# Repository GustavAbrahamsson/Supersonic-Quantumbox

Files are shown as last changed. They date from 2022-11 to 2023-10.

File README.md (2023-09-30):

# Supersonic-Quantumbox

Multi-use digital guitar pedal

## Features
This pedal is an experiment in digital sound processing, powered by an ESP32-S2 running arduino. Designed to be ultra-flexible, it has a wide array of controls and indicators including knobs, lights, a screen, true bypass switch and easily available expansions. The high performance analog components from texas instruments handle 24bit data at 48KHz. 

## Todo
This project is still WIP, alot of things can be improved to make the pedal as easy and fun as possible.

- [x] Menu system for managing multiple effects at the same time
- [x] Nice looking and sturdy enclosure
- [ ] Add lots different of effects
- [ ] Expansion port for expression pedals, switches and more
- [ ] PCB revision with ESP32-S3, better power supply filtering, footprint fixes
- [ ] Wi-Fi configuration?

Apart from this the pedal is designed to be an exploration platform for different DSP techniques and algorithms, so new effects will hopefully be added continously.

## Creators
- Adam Anderson (@adaand00): PCB, low-level drivers
- Gustav Abrahamsson (@GustavAbrahamsson): PCB, Enclosure design

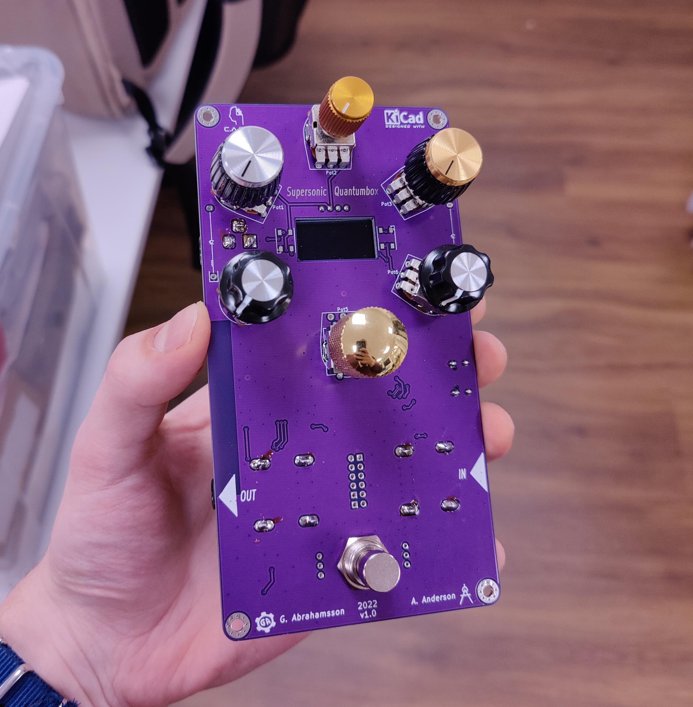
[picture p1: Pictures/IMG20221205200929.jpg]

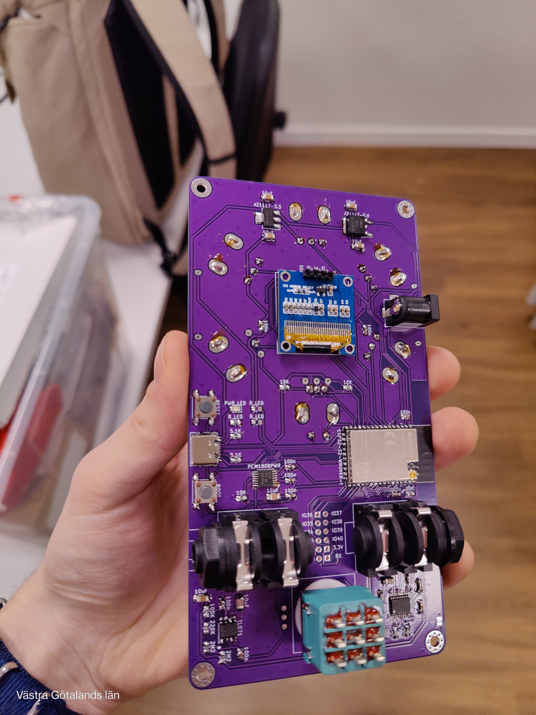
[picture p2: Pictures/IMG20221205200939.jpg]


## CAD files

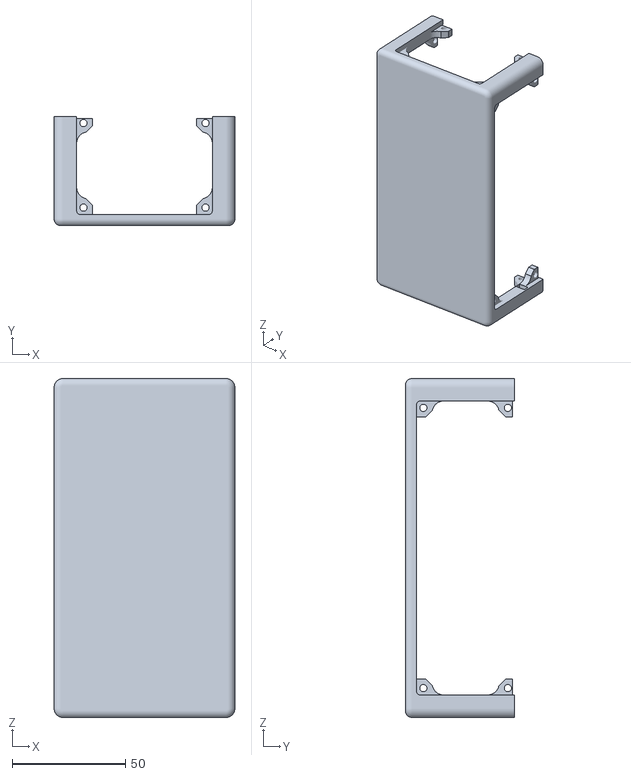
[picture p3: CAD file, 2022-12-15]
CAD/Bottom1.0.stl
80.0 x 48.4 x 150.0

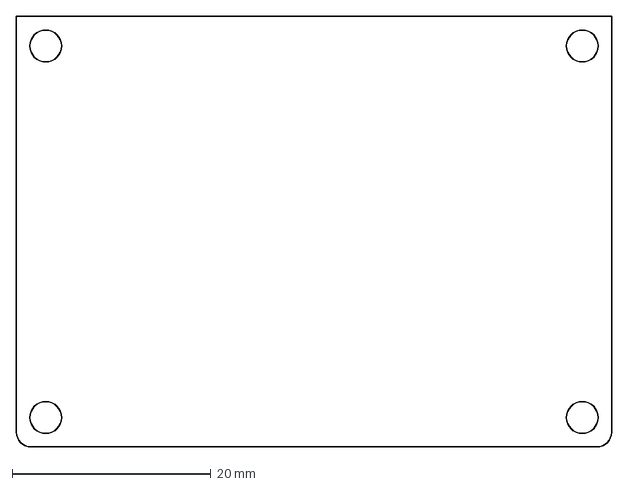
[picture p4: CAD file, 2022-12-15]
CAD/DXF/Short side 1.0.dxf
59.9 x 43.3 mm

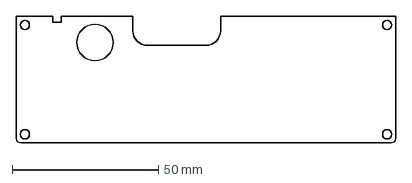
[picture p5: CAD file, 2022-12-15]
CAD/DXF/Right side 1.0.dxf
129.9 x 43.3 mm

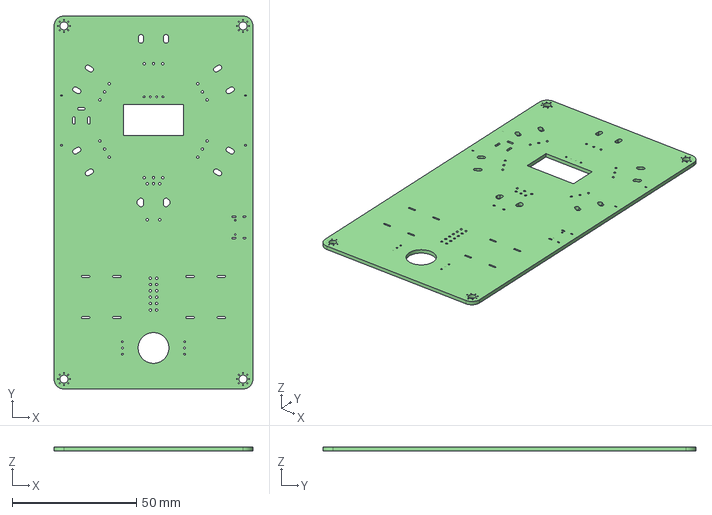
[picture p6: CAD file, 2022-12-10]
CAD/Supersonic Quantumbox.step
80.0 x 150.0 x 1.60 mm

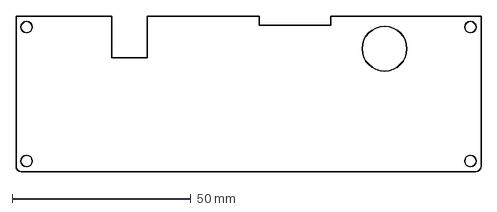
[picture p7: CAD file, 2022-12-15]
CAD/DXF/Left side 1.0.dxf
129.9 x 43.3 mm

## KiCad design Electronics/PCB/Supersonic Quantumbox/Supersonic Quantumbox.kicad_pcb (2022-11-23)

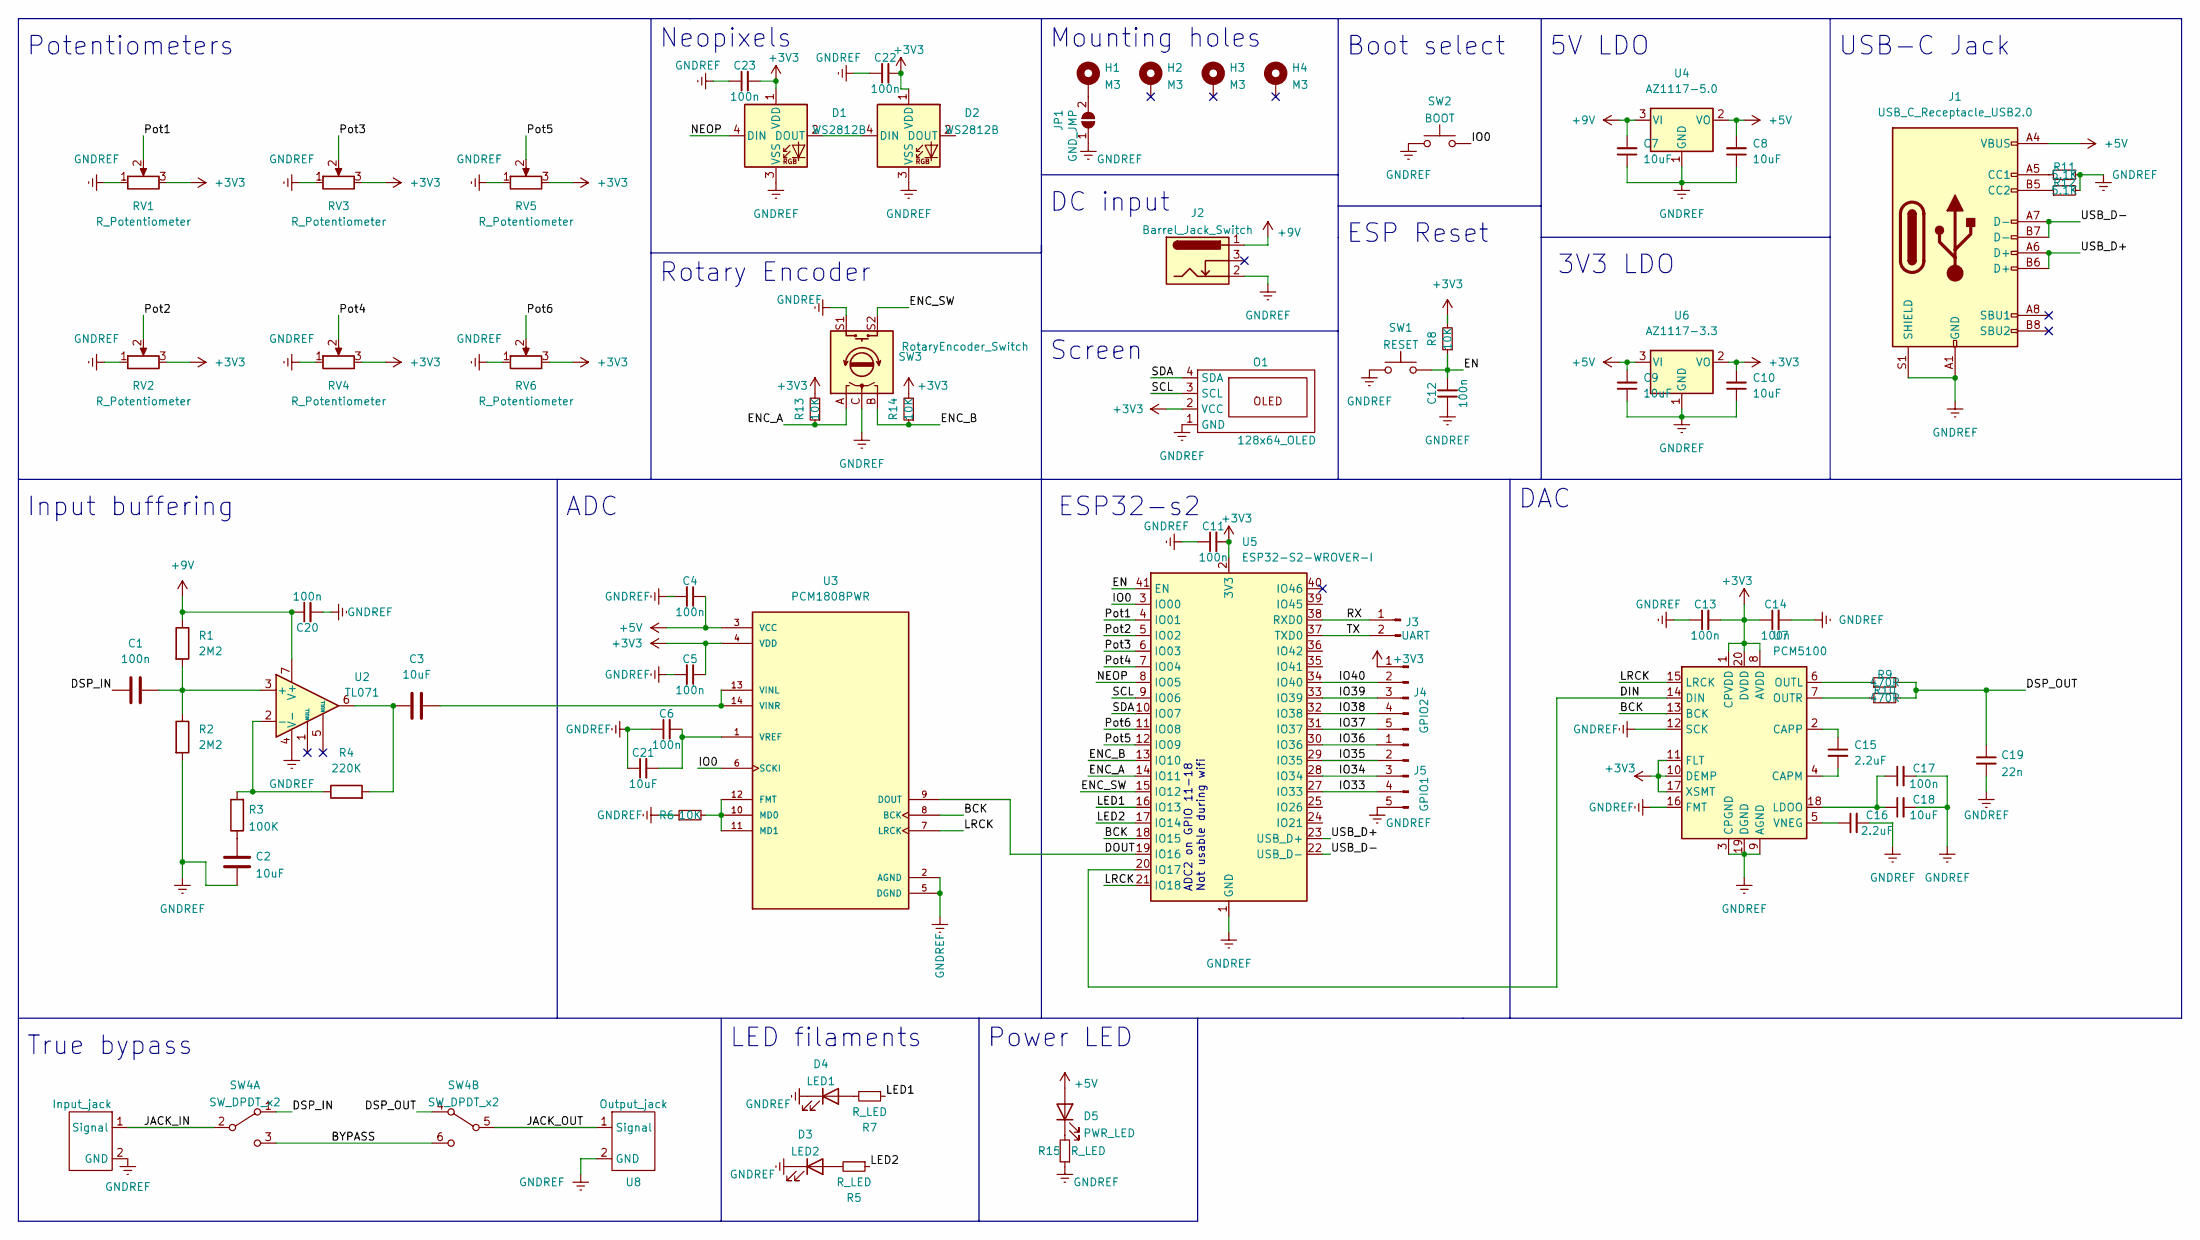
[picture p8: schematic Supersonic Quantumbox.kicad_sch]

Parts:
C1, C4, C5, C6, C11, C12, C13, C14, C17, C20, C22, C23: 100n; C_0805_2012Metric_Pad1.18x1.45mm_HandSolder
C2, C3, C7, C8, C9, C10, C18, C21: 10uF; C_1206_3216Metric
C15, C16: 2.2uF; C_1206_3216Metric
C19: 22n; C_0805_2012Metric_Pad1.18x1.45mm_HandSolder
D1, D2: WS2812B; LED_WS2812B_PLCC4_5.0x5.0mm_P3.2mm
D3: LED2; 38 mm LED
D4: LED1; 38 mm LED
D5: PWR_LED; LED_0805_2012Metric_Pad1.15x1.40mm_HandSolder
H1, H2, H3, H4: M3; MountingHole_3.2mm_M3_Pad_Via
J1: USB_C_Receptacle_USB2.0; USB_C_Receptacle_HRO_TYPE-C-31-M-12
J2: Barrel_Jack_Switch; BarrelJack_Horizontal
J3: UART; PinHeader_1x02_P2.54mm_Vertical
J4: GPIO2; PinSocket_1x05_P2.54mm_Vertical
J5: GPIO1; PinSocket_1x05_P2.54mm_Vertical
JP1: GND_JMP; SolderJumper-2_P1.3mm_Open_TrianglePad1.0x1.5mm
O1: 128x64_OLED; 128x64OLED
R1, R2: 2M2; R_0805_2012Metric_Pad1.20x1.40mm_HandSolder
R3: 100K; R_0805_2012Metric_Pad1.20x1.40mm_HandSolder
R4: 220K; R_0805_2012Metric_Pad1.20x1.40mm_HandSolder
R5, R7, R15: R_LED; R_0805_2012Metric_Pad1.20x1.40mm_HandSolder
R6, R8, R13, R14: 10K; R_0805_2012Metric_Pad1.20x1.40mm_HandSolder
R9, R10: 470R; R_0805_2012Metric_Pad1.20x1.40mm_HandSolder
R11, R12: 5.1K; R_0805_2012Metric_Pad1.20x1.40mm_HandSolder
RV1, RV2, RV3, RV4, RV5, RV6: R_Potentiometer; PBD12 potentiometer
SW1: RESET; SW_Push_1P1T_NO_6x6mm_H9.5mm
SW2: BOOT; SW_Push_1P1T_NO_6x6mm_H9.5mm
SW3: RotaryEncoder_Switch; RotaryEncoder_Alps_EC12E-Switch_Vertical_H20mm
SW4: SW_DPDT_x2; Stomp_switch
U1: Input_jack; MonoJack-SYS212
U2: TL071; SOIC-8_3.9x4.9mm_P1.27mm
U3: PCM1808PWR; SOP65P640X120-14N; PARTREV B
U4: AZ1117-5.0; TO-252-2
U5: ESP32-S2-WROVER-I; ESP32-S2-WROVER
U6: AZ1117-3.3; SOT-223-3_TabPin2
U7: PCM5100; TSSOP-20_4.4x6.5mm_P0.65mm
U8: Output_jack; MonoJack-SYS212

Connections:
+3V3: C5.1, C10.2, C11.2, C13.2, C14.1, C22.2, C23.2, D1.1 (VDD), D2.1 (VDD), J4.1, O1.2 (VCC), R8.2, R13.2, R14.2, RV1.3, RV2.3, RV3.3, RV4.3, RV5.3, RV6.3, U3.4 (VDD), U5.2 (3V3), U6.2 (VO), U7.1 (CPVDD), U7.8 (AVDD), U7.10 (DEMP), U7.11 (FLT), U7.17 (XSMT), U7.20 (DVDD)
+5V: C4.1, C8.2, C9.2, D5.2 (A), J1.A4 (VBUS), J1.A9 (VBUS), J1.B4 (VBUS), J1.B9 (VBUS), U3.3 (VCC), U4.2 (VO), U6.3 (VI)
+9V: C7.2, C20.1, J2.1, R1.1, U2.7 (V+), U4.3 (VI)
/BCK: U3.8 (BCK), U5.18 (IO15), U7.13 (BCK)
/BYPASS: SW4.3 (C), SW4.6 (C)
/DIN: U5.20 (IO17), U7.14 (DIN)
/DOUT: U3.9 (DOUT), U5.19 (IO16)
/DSP_IN: C1.1, SW4.1 (A)
/DSP_OUT: C19.1, R9.2, R10.2, SW4.4 (A)
/EN: C12.2, R8.1, SW1.2, U5.41 (EN)
/ENC_A: R13.1, SW3.A, U5.14 (IO11)
/ENC_B: R14.1, SW3.B, U5.13 (IO10)
/ENC_SW: SW3.S2, U5.15 (IO12)
/IO0: SW2.2, U3.6 (SCKI), U5.3 (IO00)
/IO33: J5.4, U5.27 (IO33)
/IO34: J5.3, U5.28 (IO34)
/IO35: J5.2, U5.29 (IO35)
/IO36: J5.1, U5.30 (IO36)
/IO37: J4.5, U5.31 (IO37)
/IO38: J4.4, U5.32 (IO38)
/IO39: J4.3, U5.33 (IO39)
/IO40: J4.2, U5.34 (IO40)
/JACK_IN: SW4.2 (B), U1.1 (Signal)
/JACK_OUT: SW4.5 (B), U8.1 (Signal)
/LED1: R7.1, U5.16 (IO13)
/LED2: R5.1, U5.17 (IO14)
/LRCK: U3.7 (LRCK), U5.21 (IO18), U7.15 (LRCK)
/NEOP: D1.4 (DIN), U5.8 (IO05)
/Pot1: RV1.2, U5.4 (IO01)
/Pot2: RV2.2, U5.5 (IO02)
/Pot3: RV3.2, U5.6 (IO03)
/Pot4: RV4.2, U5.7 (IO04)
/Pot5: RV5.2, U5.12 (IO09)
/Pot6: RV6.2, U5.11 (IO08)
/RX: J3.1, U5.38 (RXD0)
/SCL: O1.3 (SCL), U5.9 (IO06)
/SDA: O1.4 (SDA), U5.10 (IO07)
/TX: J3.2, U5.37 (TXD0)
/USB_D+: J1.A6 (D+), J1.B6 (D+), U5.23 (USB_D+)
/USB_D-: J1.A7 (D-), J1.B7 (D-), U5.22 (USB_D-)
GNDREF: C2.1, C4.2, C5.2, C6.1, C7.1, C8.1, C9.1, C10.1, C11.1, C12.1, C13.1, C14.2, C16.2, C17.2, C18.2, C19.2, C20.2, C21.1, C22.1, C23.1, D1.3 (VSS), D2.3 (VSS), D3.1 (K), D4.1 (K), J1.A1 (GND), J1.A12 (GND), J1.B1 (GND), J1.B12 (GND), J1.S1 (SHIELD), J2.2, J5.5, JP1.1 (A), O1.1 (GND), R2.2, R6.1, R11.2, R12.2, R15.1, RV1.1, RV2.1, RV3.1, RV4.1, RV5.1, RV6.1, SW1.1, SW2.1, SW3.C, SW3.S1, U1.2 (GND), U2.4 (V-), U3.2 (AGND), U3.5 (DGND), U4.1 (GND), U5.1 (GND), U5.26 (GND), U5.42 (GND), U5.43 (GND), U6.1 (GND), U7.3 (CPGND), U7.9 (AGND), U7.12 (SCK), U7.16 (FMT), U7.19 (DGND), U8.2 (GND)
unnamed: C1.2, R1.2, R2.1, U2.3 (+)
unnamed: C2.2, R3.1
unnamed: C3.1, R4.2, U2.6
unnamed: C3.2, U3.13 (VINL), U3.14 (VINR)
unnamed: C15.1, U7.2 (CAPP)
unnamed: C15.2, U7.4 (CAPM)
unnamed: C16.1, U7.5 (VNEG)
unnamed: C17.1, C18.1, U7.18 (LDOO)
unnamed: C6.2, C21.2, U3.1 (VREF)
unnamed: D1.2 (DOUT), D2.4 (DIN)
unnamed: D3.2 (A), R5.2
unnamed: D4.2 (A), R7.2
unnamed: D5.1 (K), R15.2
unnamed: H1.1, JP1.2 (B)
unnamed: J1.A5 (CC1), R11.1
unnamed: J1.B5 (CC2), R12.1
unnamed: R3.2, R4.1, U2.2 (-)
unnamed: R6.2, U3.10 (MD0), U3.11 (MD1), U3.12 (FMT)
unnamed: R9.1, U7.6 (OUTL)
unnamed: R10.1, U7.7 (OUTR)

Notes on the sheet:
ADC
Mounting holes
ESP Reset
True bypass
Screen
ESP32-s2
3V3 LDO
ADC2 on GPIO 11-18 Not usable during wifi
Power LED
LED filaments
Boot select
Rotary Encoder
DC input
DAC
Neopixels
Potentiometers
5V LDO
Input buffering
USB-C Jack

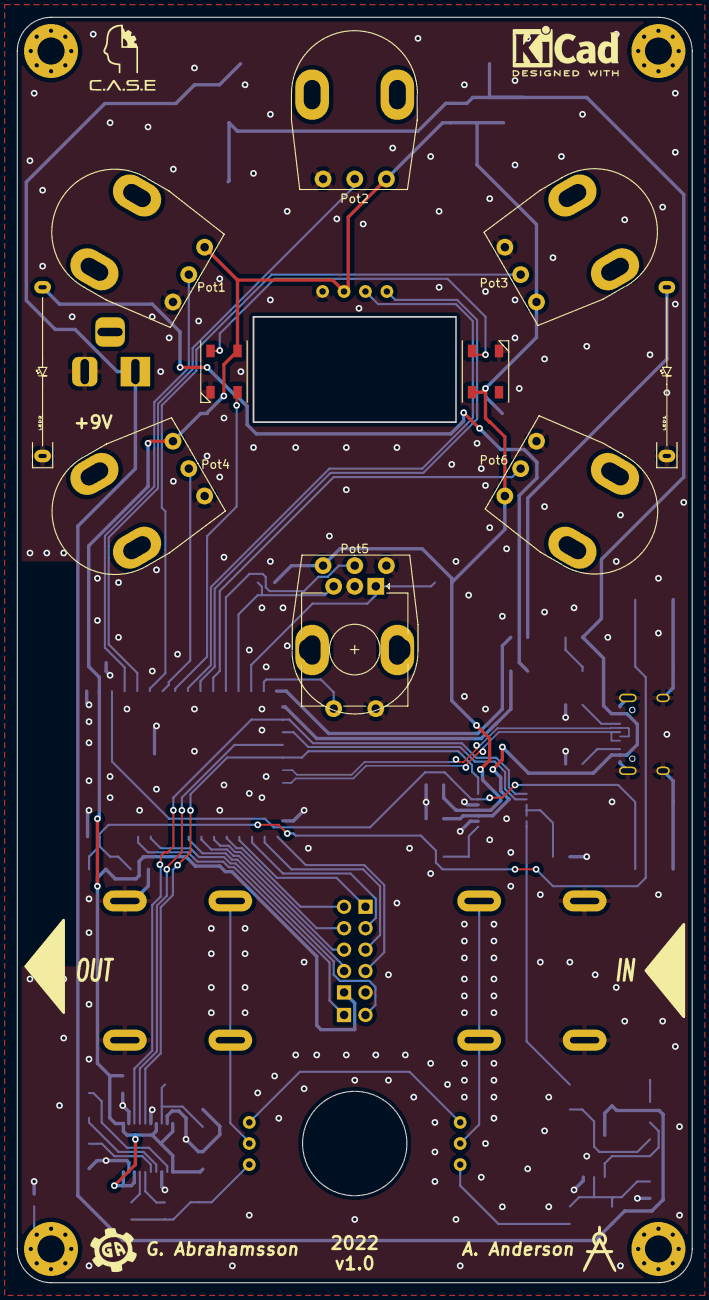
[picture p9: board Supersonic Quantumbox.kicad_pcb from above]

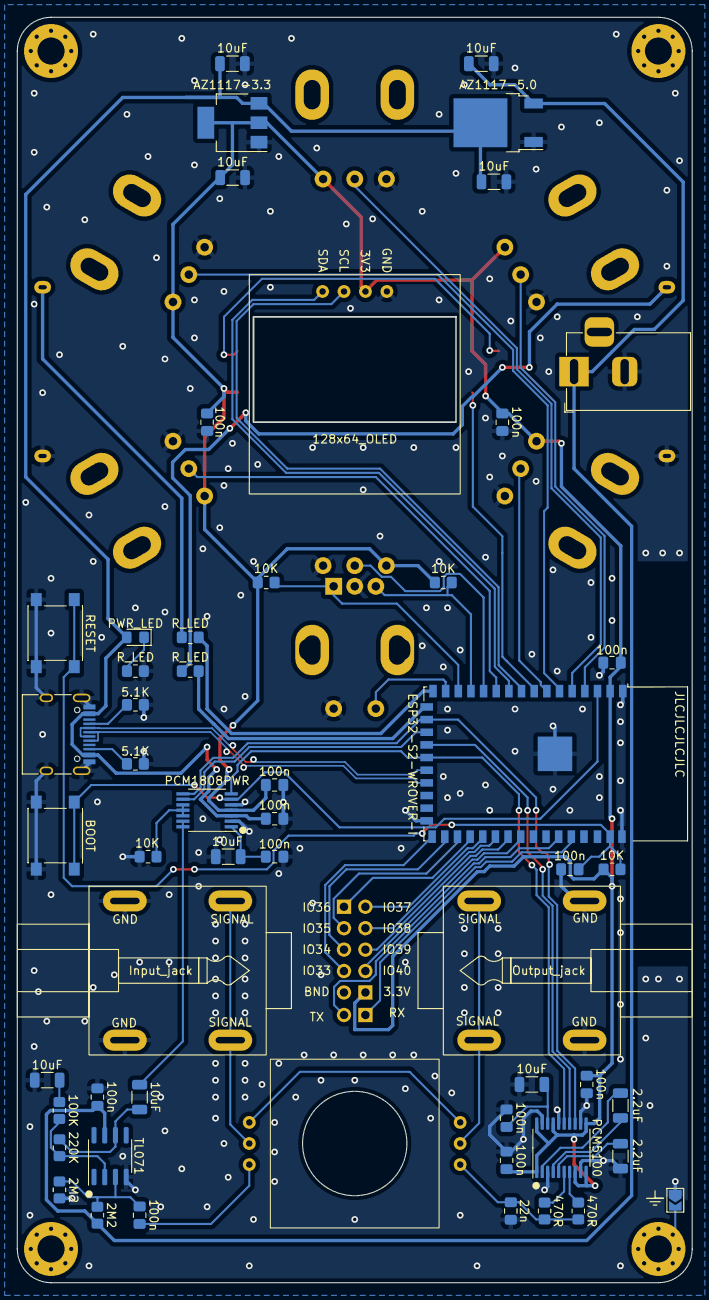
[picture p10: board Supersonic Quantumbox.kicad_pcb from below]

Board: 2 copper layers, 80.0 x 150.0 mm, 72 parts (53 on the bottom side), 61 nets.

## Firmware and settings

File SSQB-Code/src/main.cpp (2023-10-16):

#include <Arduino.h>
#include <NeoPixelBus.h>
#include <ESP32Encoder.h>
#include "driver/i2s.h"
//#include "dsps_fft2r.h"
#include "Adafruit_GFX.h"
#include "Adafruit_SSD1306.h"

#pragma GCC diagnostic warning "-Wpedantic" // Enable pedantic warnings for own code
#pragma GCC optimize("O3")                  // Optimize for speed
#pragma GCC optimize("fast-math")           // Enable fast math (Lower accuracy)

// Project libraries
#include <MenuHelper.h>
#include <GenericEffect.h>

// Effects
#include <Clip.h>
#include <Meter.h>
#include <DelayEffect.h>
#include <Saturation.h>
#include <Gain.h>
#include <Square.h>
#include <NoiseGate.h>
#include <Peak.h>
#include <DiffuserEffect.h>
#include <Scope.h>


// --------------CONFIG-----------------------
// comment out to disable

#define USE_OLED
#define USE_ENCODER
#define USE_PIXELS
//#define USE_LEDS
#define USE_TRUE_BP


// Set to true to enable pot
bool POTS_ENABLED[6] = {true, true, true, false, false, false};

// ----------------Pins-----------------------
#define POT1      GPIO_NUM_1
#define POT2      GPIO_NUM_2
#define POT3      GPIO_NUM_3
#define POT4      GPIO_NUM_4
#define PIXELPIN  GPIO_NUM_5
#define SCL       GPIO_NUM_6
#define SDA       GPIO_NUM_7
#define POT6      GPIO_NUM_8
#define POT5      GPIO_NUM_9
#define ENC_B     GPIO_NUM_10
#define ENC_A     GPIO_NUM_11
#define ENC_SW    GPIO_NUM_12
#define LED1      GPIO_NUM_13
#define LED2      GPIO_NUM_14
#define BCLK      GPIO_NUM_15
#define DIN       GPIO_NUM_16
#define DOUT      GPIO_NUM_17
#define LRCLK     GPIO_NUM_18
#define TRUE_BP   GPIO_NUM_37 // Used on Gustav's pedal

// ----------Global variables-----------------

// Effects
Meter MaxInputMeter;
Clip outputClip;
DelayEffect delayEffect;
Meter maxOutputMeter;
Saturation saturationEffect;
Square squareEffect;
NoiseGate noiseGate;
Peak peakEffect;
DiffuserEffect diffuserEffect;
Scope scopeEffect;

GenericEffect * effects[] = {
  &noiseGate,
  &saturationEffect,
  &diffuserEffect,
  //&peakEffect,
  //&squareEffect,
  &maxOutputMeter,
  //&delayEffect, 
  &outputClip,
  &scopeEffect,
};

const uint32_t numEffects = sizeof(effects)/sizeof(effects[0]);

// Bindings for each pot 
// potToEffect[potNum] = effectNum
int8_t potToEffect[] = {1, 1, 1, 1, 1, 1};

// DSP variables
#define I2S_NUM   I2S_NUM_0
#define BUFFSIZE  128
#define F_MUL (float)INT32_MAX
#define F_DIV (float)(1.0f/INT32_MAX)

int32_t i2s_write_buff[BUFFSIZE*2];
int32_t i2s_read_buff[BUFFSIZE*2];
float avgDspTime = 0;

// True: true bypass, the signal is skipping the pedal
// False: the signal is passing through the pedal
volatile bool trueBypass = false;

// Neopixel
#ifdef USE_PIXELS
  int pixelCount = 2;
  RgbColor pixelColors[] = {RgbColor(64,0,0), RgbColor(0,0,0)};
  NeoPixelBus<NeoGrbFeature, Neo800KbpsMethod> strip(pixelCount, PIXELPIN);
#endif

// Encoder
#ifdef USE_ENCODER
  ESP32Encoder encoder;
  bool encoderButton = false;
  int32_t encoderCount = 0;
#endif

// potentiometers
float pots[6];
#define F_POTS (1.0f/8196.0f)
gpio_num_t potPins[6] = {POT1, POT2, POT3, POT4, POT5, POT6};

//deadband for pots
bool potsChanged[6] = {false, false, false, false, false, false};
uint32_t potsLastChanged[6] = {0, 0, 0, 0, 0, 0};
#define POTS_CHANGED_THRESHOLD 0.03f

// OLED
#ifdef USE_OLED
  TwoWire OledWire = TwoWire(0);
  Adafruit_SSD1306 display(128, 64, &OledWire, -1);

  PedalContext ctx = {
    effects,
    numEffects,
    &display,
    0,
    0
  };

  MenuHelper menuHelper = NULL;
#endif

// Macro for debug output during startup
#ifdef USE_OLED
  #define debugPrint(x) {display.println(x); display.display(); log_i(x);}
#else
  #define debugPrint(x) {Serial.println(x);}
#endif

// LED filaments
#ifdef USE_LEDS
  int ledBrightness[] = {0, 0};
#endif

// Is executed every time the switch changes
volatile uint32_t lastSwitchChange = 0;
#define DEBOUNCE_TIME_MS 20
void IRAM_ATTR switchISR() {
    //display.println("MAIN SWITCH EVENT2");
    //Serial.println("MAIN SWITCH EVENT 2");
    
    // Avoid bouncing by only allowing switch-changes at least DEBOUNCE_TIME_MS apart
    if (millis() - lastSwitchChange > DEBOUNCE_TIME_MS){
      lastSwitchChange = millis();
      trueBypass = digitalRead(TRUE_BP);

      // write to neopixels
      #ifdef USE_PIXELS
        // Red for "active"
        if (trueBypass) strip.SetPixelColor(0, pixelColors[0]);
        else strip.SetPixelColor(0, RgbColor(0,0,0));
        
        strip.SetPixelColor(1, pixelColors[1]);
        strip.Show();
      #endif
    
  }
}


// --------------Functions--------------------

void install_i2s(){
  // Don't need these warnings, this code is from espressif docs
  #pragma GCC diagnostic push
  #pragma GCC diagnostic ignored "-Wpedantic"
  #pragma GCC diagnostic ignored "-Wmissing-field-initializers"

  // I2S
  i2s_config_t i2s_config = {
    .mode = (i2s_mode_t) (I2S_MODE_MASTER | I2S_MODE_TX | I2S_MODE_RX), // Both TX and RX in master mode
    .sample_rate = 48000,
    .bits_per_sample = I2S_BITS_PER_SAMPLE_32BIT,
    .channel_format = I2S_CHANNEL_FMT_RIGHT_LEFT,
    .communication_format = I2S_COMM_FORMAT_STAND_I2S,
    .intr_alloc_flags = ESP_INTR_FLAG_LEVEL1, 
    .dma_buf_count = 4,
    .dma_buf_len = BUFFSIZE,
    .use_apll = true,
    .tx_desc_auto_clear = true,
    .mclk_multiple = I2S_MCLK_MULTIPLE_256,
  };

  i2s_pin_config_t pin_config = {
    .mck_io_num = 0,
    .bck_io_num = BCLK,
    .ws_io_num = LRCLK,
    .data_out_num = DOUT,
    .data_in_num = DIN
  };

  #pragma GCC diagnostic pop

  ESP_ERROR_CHECK(i2s_driver_install(I2S_NUM, &i2s_config, 0, NULL));
  ESP_ERROR_CHECK(i2s_set_pin(I2S_NUM, &pin_config));
}

void AudioTask(void *pvParameters){

  // Wait for input buffer to fill up
  delay(1000);

  while(1){

    // Read from I2S
    size_t bytes_written;
    ESP_ERROR_CHECK(i2s_read(I2S_NUM, (char *) i2s_read_buff, BUFFSIZE*2*sizeof(int32_t), &bytes_written, portMAX_DELAY));
    uint32_t startTime = micros();

    // Send to a chunk to DSP function, one sample at a time
    for (int i = 0; i < BUFFSIZE; i++)
    {
      //Save current sample
      float s = ((float) i2s_read_buff[i * 2])*F_DIV;

      // Call DSP function for modified sample
      for (int e = 0; e < numEffects; e++)
      {
        s = effects[e]->DSP(s);
      }

      int32_t si = s*F_MUL;
      //Write sample to I2S buffer
      i2s_write_buff[i * 2] = si;
      i2s_write_buff[i * 2 + 1] = si;
    }

    // Calculate DSP time
    uint32_t DSPTime = micros() - startTime;
    float DSPpct = DSPTime*(48000.0f/(BUFFSIZE*1000000.0f));
    avgDspTime = (avgDspTime * 0.95f) + (DSPpct * 0.05f);

    // Write to I2S
    ESP_ERROR_CHECK(i2s_write(I2S_NUM, (const char*) &i2s_write_buff, BUFFSIZE *2* sizeof(int32_t), &bytes_written, portMAX_DELAY));
  }
}

void PeripheralTask(void *pvParameters){
  TickType_t LastWakeTime = xTaskGetTickCount();
  float taskFrequency = 5; // Hz
  float taskMillis = 1000.0 / taskFrequency;
  const TickType_t xFrequency = pdMS_TO_TICKS(taskMillis);
  
  #ifdef USE_OLED
    //uint32_t maxRam = ESP.getPsramSize();
    
    int32_t lastEncoderCount = 0;
    uint32_t encoderButtonCount = 0;
    menuHelper = MenuHelper(&ctx);
    bool buttonHeld = false;
  #endif

  while(1){

    // send pot values to effects
    for(int i = 0; i<6; i++){
      if(POTS_ENABLED[i]){
        int8_t effectNum = potToEffect[i];
        if(effectNum != -1 && potsChanged[i] && effects[effectNum]->getNumInputs() > i)
          effects[effectNum]->setInputValue(i, pots[i]);        
      }
    }
    
    // Read encoder
    #ifdef USE_ENCODER
      encoderCount = encoder.getCount()/2;
      encoderButton = !digitalRead(ENC_SW);
      encoderButtonCount += encoderButton;
    #endif

    // write to OLED
    #ifdef USE_OLED

      if(!encoderButton && encoderButtonCount > 0 && encoderButtonCount < 5 && !buttonHeld){
        menuHelper.HandleInput(MENU_PRESS);
        encoderButtonCount = 0;
      }else if (encoderButton && encoderButtonCount >= 5 && !buttonHeld){
        menuHelper.HandleInput(MENU_HOLD);
        buttonHeld = true;
      }else if (!encoderButton && buttonHeld){
        encoderButtonCount = 0;
        buttonHeld = false;
      }else if (encoderCount > lastEncoderCount){
        menuHelper.HandleInput(MENU_LEFT);
        lastEncoderCount += 1;
      }else if (encoderCount < lastEncoderCount){
        menuHelper.HandleInput(MENU_RIGHT);
        lastEncoderCount -= 1;
      }else{
        menuHelper.UpdateDisplay();
      }

    #endif

    //write to LED filaments
    #ifdef USE_LEDS
      ledcWrite(0, ledBrightness[0]);
      ledcWrite(1, ledBrightness[1]);
    #endif

    // vTaskDelayUntil(&LastWakeTime, xFrequency);
    vTaskDelay(xFrequency);

  }
}

void potLoop(void *pvParameters){
  TickType_t LastWakeTime = xTaskGetTickCount();
  uint16_t taskFrequency = 100; // Hz
  uint16_t taskMillis = 1000.0 / taskFrequency;
  const TickType_t xFrequency = pdMS_TO_TICKS(taskMillis);

  // FIR filter for smoothing pots
  while(1){
    for (int i = 0; i < 6; i++)
    {
      if(POTS_ENABLED[i]){
        float oldVal = pots[i];
        float newVal = analogRead(potPins[i])*F_POTS;

        // Linear for a short amount of time after a change
        if (potsChanged[i]){
          if (millis() - potsLastChanged[i] < 500){
            pots[i] = newVal;
          } else {
            potsChanged[i] = false;
          }
        }

        // If the pot has changed, update the value, reset time
        if(abs(newVal - oldVal) > POTS_CHANGED_THRESHOLD){
          potsChanged[i] = true;
          pots[i] = newVal;
          potToEffect[i] = ctx.CurrentEffectNum;
          potsLastChanged[i] = millis();
        }

      }
    }

    vTaskDelayUntil(&LastWakeTime, xFrequency);
  }
}



void setup() {

  delay(3000); // If it crashes after the delay, there is time to upload

  // put your setup code here, to run once:¨
  //#ifndef USE_OLED
    Serial.begin(115200);
    Serial.setDebugOutput(true);
  //#endif

  // Initialize OLED
  #ifdef USE_OLED
    OledWire.setPins(SDA, SCL);
    display.begin(SSD1306_SWITCHCAPVCC, 0x3C, false, true);
    display.clearDisplay();
    display.setTextColor(1);
    display.println("SUPERSONIC QUANTUMBOX");
    display.display();
    display.setFont(&Picopixel);

    debugPrint("OLED initialized");
  #endif

  // Initialize the strip
  #ifdef USE_PIXELS
    strip.Begin();
    strip.Show();
    debugPrint("Strip initialized");
  #endif

  // Initialize the encoder
  #ifdef USE_ENCODER
    encoder.attachHalfQuad(ENC_A, ENC_B);
    encoder.clearCount();
    pinMode(ENC_SW, INPUT_PULLUP);
    debugPrint("Encoder initialized");
  #endif

  // Initialize I2S
  install_i2s();
  debugPrint("I2S initialized");

  delay(1000);

  // If the state of the switch (true bypass) is measured at pin 'TRUE_BP'
  #ifdef USE_TRUE_BP
    pinMode(TRUE_BP, INPUT);
    trueBypass = digitalRead(TRUE_BP);
    attachInterrupt(digitalPinToInterrupt(TRUE_BP), switchISR, CHANGE);
    debugPrint("ISR initialized");
  #endif

  // Initialize the pots
  analogSetAttenuation(ADC_11db);
  for (int i = 0; i < 6; i++)
  {
    if(POTS_ENABLED[i]){
      pinMode(potPins[i], INPUT);
      pots[i] = analogRead(potPins[i]);
    }
  }
  debugPrint("Pots initialized");

  // Initialize LED filament
  #ifdef USE_LEDS
    pinMode(LED1, OUTPUT);
    ledcAttachPin(LED1, 0);
    ledcSetup(0, 1000, 8);
    ledcWrite(0, 0);

    pinMode(LED2, OUTPUT);
    ledcAttachPin(LED2, 1);
    ledcSetup(1, 1000, 8);
    ledcWrite(1, 0);
    debugPrint("LEDs initialized");
  #endif

  // Start the audio task
  psramInit();
  debugPrint("PSRAM initialized");

  // Initialize effects
  for(int i = 0; i < numEffects; i++){
    effects[i]->init();
  }
  
  delay(1000);
  // Start audio task
  xTaskCreate(AudioTask, "AudioTask", 10000, NULL, 10, NULL);
  //display.clearDisplay();
  //display.setCursor(0, 4);
  debugPrint("Audio task started");

  delay(1000);

  // Start pot task
  xTaskCreate(potLoop, "potLoop", 10000, NULL, 1, NULL);
  debugPrint("PotLoop started");

  delay(1000);
  // Start peripheral task
  // TODO: Split updating display and handling input into two tasks
  xTaskCreate(PeripheralTask, "PeripheralTask", 10000, NULL, 1, NULL);
  // Do not use display after this point, it is used by the peripheral task
}

void loop() {
  delay(50000);
}

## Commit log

2022-11-01 Init project and PCB
    [Supersonic Quantumbox.kicad_pcb, Supersonic Quantumbox.kicad_sch]
2022-11-01 Develop PCB
    [Supersonic Quantumbox.kicad_pcb, Supersonic Quantumbox.kicad_sch]
2022-11-01 Start work on PCB
    [Supersonic Quantumbox.kicad_pcb, Supersonic Quantumbox.kicad_sch]
2022-11-02 POT and screen adjustment
    [Supersonic Quantumbox.kicad_pcb, Supersonic Quantumbox.kicad_sch]
2022-11-02 Change PCB layout
    [Supersonic Quantumbox.kicad_pcb, Supersonic Quantumbox.kicad_sch]
2022-11-03 Begin PWR tracing
    [Supersonic Quantumbox.kicad_pcb, Supersonic Quantumbox.kicad_sch]
2022-11-03 Final routing
    [Supersonic Quantumbox.kicad_pcb]
2022-11-03 Almost finish PCB
    [Supersonic Quantumbox.kicad_pcb]
2022-11-04 Final touches
    [Supersonic Quantumbox.kicad_pcb, Supersonic Quantumbox.kicad_sch]
2022-11-04 Add Gerbs
    [Supersonic Quantumbox-B_Cu.gbr, Supersonic Quantumbox-B_Mask.gbr, Supersonic Quantumbox-B_Paste.gbr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]
2022-11-23 Start code, add pins
    [Supersonic Quantumbox.kicad_pcb]
2022-11-24 Encoder, not working
2022-11-24 Encoder and i2s compiling
2022-12-10 Begin case design
    [Supersonic Quantumbox case v6.f3z, Supersonic Quantumbox.step]
2022-12-12 Use LEDS
2022-12-12 Add LED resistor value and Improvements.txt
2022-12-13 Rework DSP function structure
    [main.cpp]
2022-12-15 Add case 1.0 files
    [Bottom1.0.stl, Left side 1.0.dxf, Right side 1.0.dxf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]
2022-12-16 Start prototype effect class
2023-03-14 Init Saturation effect with plotter
    [Supersonic Quantumbox case v6.f3z]
2023-09-27 Add red LED to show true bypass state
2023-09-28 Add FreeRTOS scheduling and fix slow button
    [main.cpp]
2023-09-29 Deadband pots, small fixes
    [main.cpp]
2023-09-30 Interrupt handler for switch, tweak RTOS
2023-10-03 Initial peaking filter, parameters not perfect
